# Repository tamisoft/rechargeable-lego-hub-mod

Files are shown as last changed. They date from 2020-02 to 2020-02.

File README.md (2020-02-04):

# LEGO HUB-mod, rechargable battery
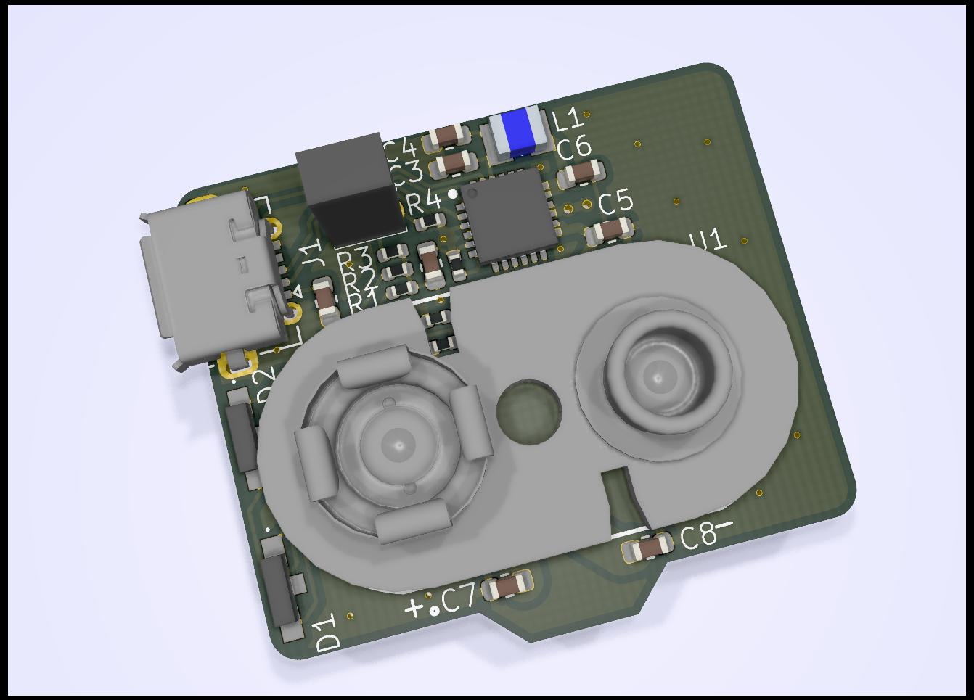
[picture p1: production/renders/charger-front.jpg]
Front Render


## Project
The Project was created using KiCAD 5.1.5.
Should be manufactured on a <0.8mm thick PCB (eg. oshpark's 2oz copper service).
The "production" directory has an "interactive bom" to assist with the hand assembly.

## Features
- USB charging at about 400mA
- TI BQ25886, 2A boost charger, optimized for 2S Li-Ion
- NTC
- connector for an 8.4V battery

Recommended battery:
[Soshine 9V 650mAh 6F22](https://lygte-info.dk/review/batteries9V/Soshine%209V%20LiIon%20650mAh%20(White)%20UK.html)

## Finished build
### Board assembled
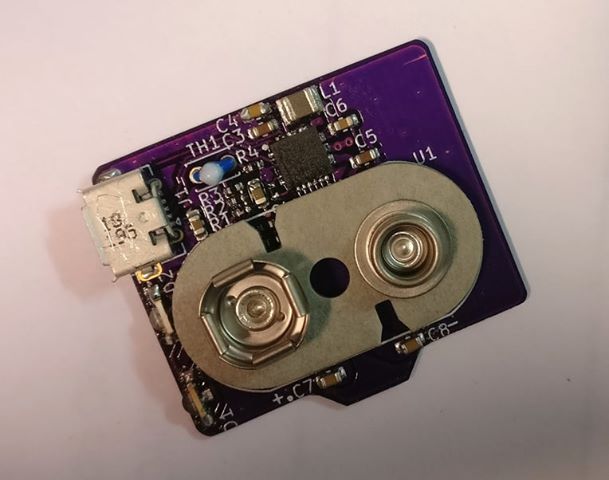
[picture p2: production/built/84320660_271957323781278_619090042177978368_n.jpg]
Board Assembled

### USB input
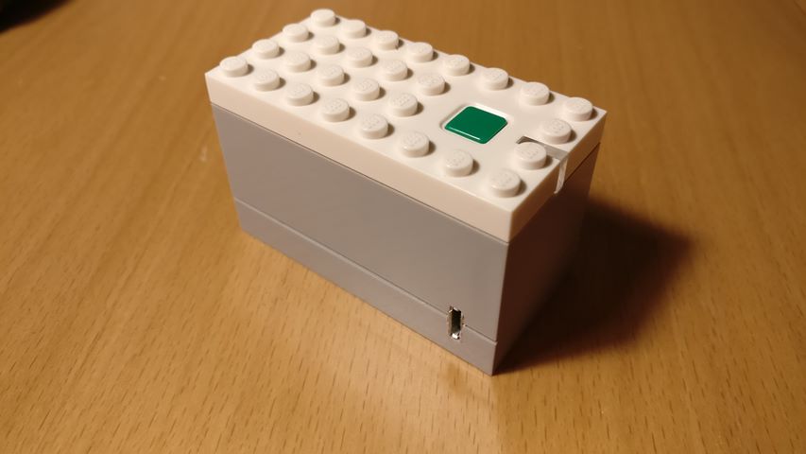
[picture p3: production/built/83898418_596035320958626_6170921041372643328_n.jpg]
USB input

### Charging indicators
- red: charging
- green: power

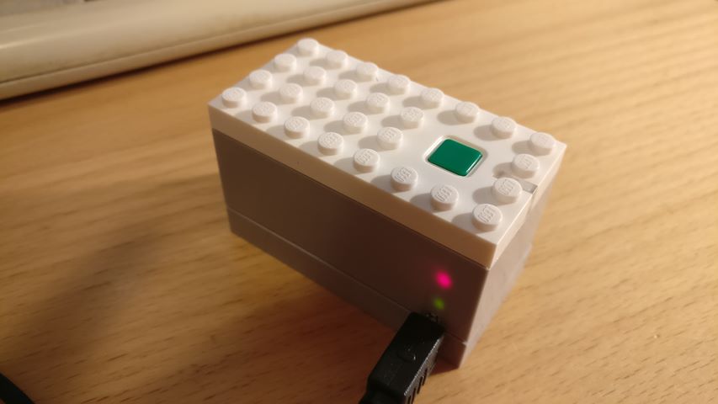
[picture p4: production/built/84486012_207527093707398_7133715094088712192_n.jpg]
Charging indicators


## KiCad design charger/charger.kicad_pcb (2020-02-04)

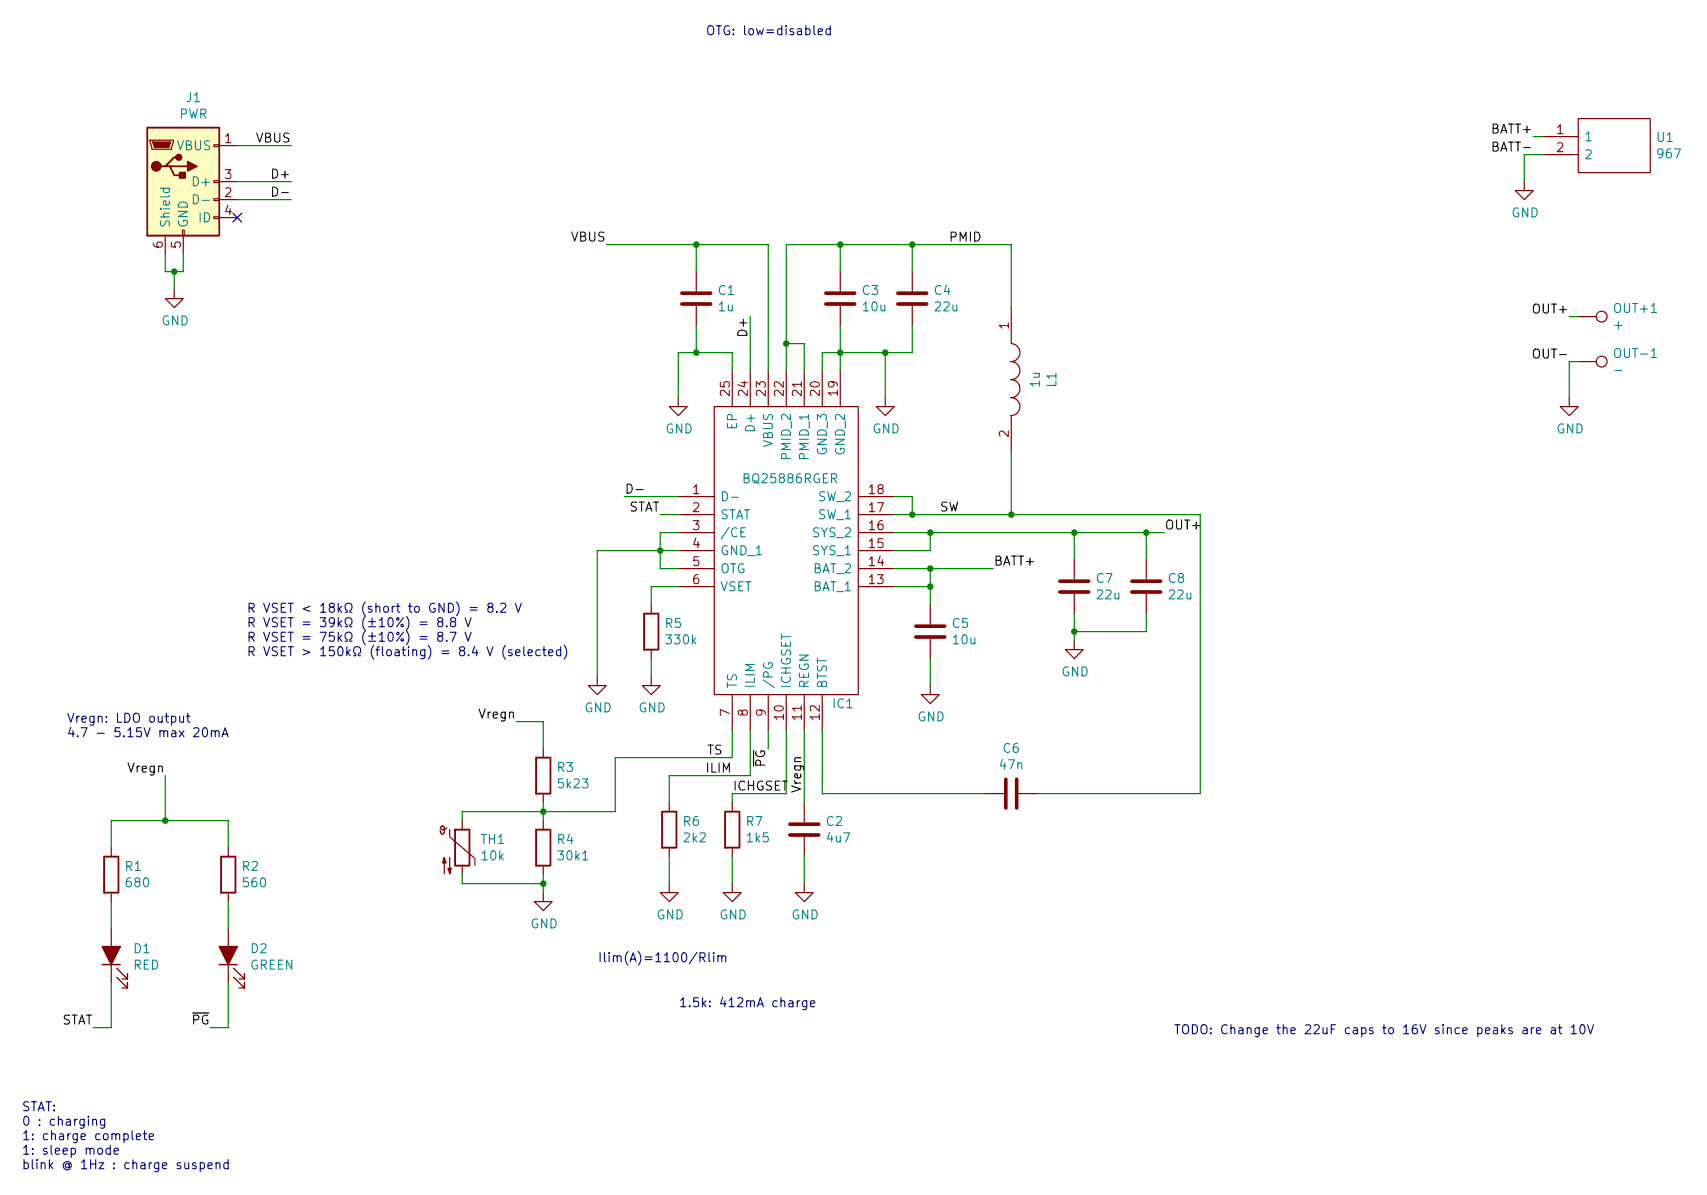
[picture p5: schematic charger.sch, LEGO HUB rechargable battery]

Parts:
C1: 1u; C_0603_1608Metric; MOUSER 603-CC603KPX7R7BB105
C2: 4u7; C_0603_1608Metric; MOUSER 963-EMK107ABJ475MA-T
C3, C5: 10u; C_0603_1608Metric; MOUSER 81-GRT188R61C106KE3D
C4, C7, C8: 22u; C_0603_1608Metric; MOUSER 81-ZRB18AR61A226ME1L
C6: 47n; C_0603_1608Metric; MOUSER 603-CC603KPX7R7BB473
D1: RED; HSMAC110; MOUSER 630-HSMH-C110
D2: GREEN; HSMAC110; MOUSER 630-HSMG-C110
IC1: BQ25886RGER; QFN50P400X400X100-25N; Mouser Part Number 595-BQ25886RGER
J1: PWR; USB_Micro-AB_Molex_47590-0001; MOUSER 538-47590-0001
L1: 1u; INDC2520X120N; Mouser Part Number 81-DFE252012F-1R0MP2
OUT+1: +; TestPoint_Pad_1.0x1.0mm
OUT-1: -; TestPoint_Pad_1.0x1.0mm
R1: 680; R_0402_1005Metric; MOUSER 667-ERJ-U02D6800X
R2: 560; R_0402_1005Metric; MOUSER 667-ERJ-2RHD5600X
R3: 5k23; R_0402_1005Metric; MOUSER 603-AC0402FR-075K23L
R4: 30k1; R_0402_1005Metric; MOUSER 667-ERJ-2RHD3012X
R5: 330k; R_0402_1005Metric; MOUSER 71-CRCW0402330KFKEDC
R6: 2k2; R_0402_1005Metric; MOUSER 279-CRGP0402F2K2
R7: 1k5; R_0402_1005Metric; MOUSER 71-CRCW04021K50FKEDC
TH1: 10k; 103AT2; MOUSER 954-103AT-2
U1: 967; Mouser Part Number 534-967

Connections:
/BATT+: C5.1, IC1.13 (BAT_1), IC1.14 (BAT_2), U1.1
/D+: IC1.24 (D+), J1.3 (D+)
/D-: IC1.1 (D-), J1.2 (D-)
/ICHGSET: IC1.10 (ICHGSET), R7.1
/ILIM: IC1.8 (ILIM), R6.1
/OUT+: C7.1, C8.1, IC1.15 (SYS_1), IC1.16 (SYS_2), OUT+1.1
/PMID: C3.1, C4.1, IC1.21 (PMID_1), IC1.22 (PMID_2), L1.1
/STAT: D1.1 (K), IC1.2 (STAT)
/SW: C6.1, IC1.17 (SW_1), IC1.18 (SW_2), L1.2
/TS: IC1.7 (TS), R3.2, R4.1, TH1.1
/VBUS: C1.1, IC1.23 (VBUS), J1.1 (VBUS)
/Vregn: C2.1, IC1.11 (REGN), R1.1, R2.1, R3.1
/~PG: D2.1 (K), IC1.9 (/PG)
GND: C1.2, C2.2, C3.2, C4.2, C5.2, C7.2, C8.2, IC1.3 (/CE), IC1.4 (GND_1), IC1.5 (OTG), IC1.19 (GND_2), IC1.20 (GND_3), IC1.25 (EP), J1.5 (GND), J1.6 (Shield), OUT-1.1, R4.2, R5.2, R6.2, R7.2, TH1.2, U1.2
unnamed: C6.2, IC1.12 (BTST)
unnamed: D1.2 (A), R1.2
unnamed: D2.2 (A), R2.2
unnamed: IC1.6 (VSET), R5.1

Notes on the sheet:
OTG: low=disabled
R VSET < 18kΩ (short to GND) = 8.2 V R VSET = 39kΩ (±10%) = 8.8 V R VSET = 75kΩ (±10%) = 8.7 V R VSET > 150kΩ (floating) = 8.4 V (selected)
STAT: 0 : charging 1: charge complete 1: sleep mode blink @ 1Hz : charge suspend
Vregn: LDO output 4.7 - 5.15V max 20mA
1.5k: 412mA charge
Ilim(A)=1100/Rlim
TODO: Change the 22uF caps to 16V since peaks are at 10V

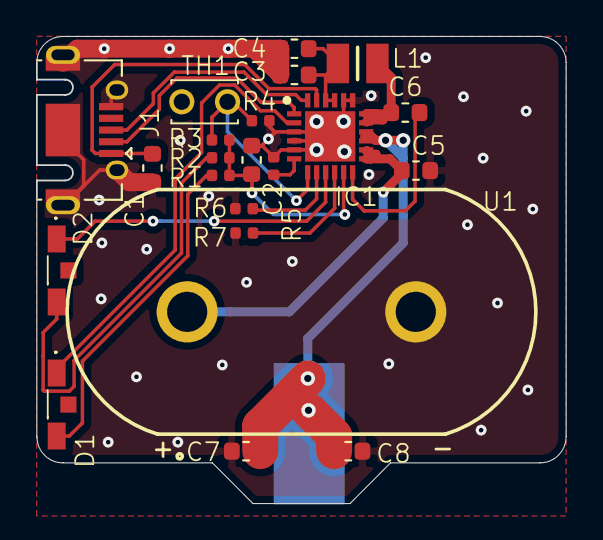
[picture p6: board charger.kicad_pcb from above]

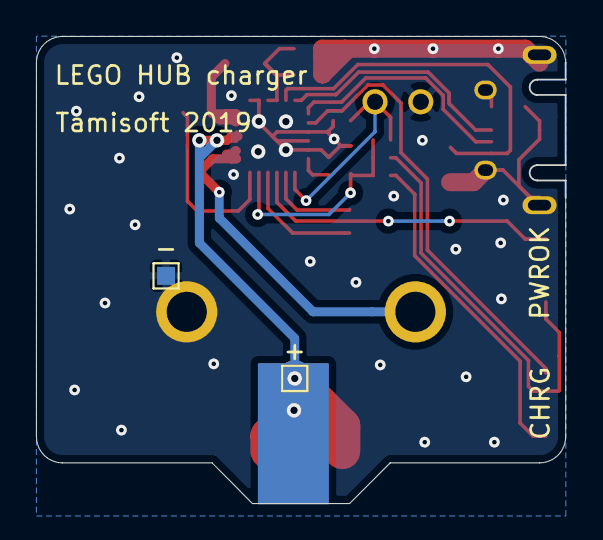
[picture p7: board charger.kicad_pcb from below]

Board: 2 copper layers, 29.4 x 26.0 mm, 24 parts (2 on the bottom side), 18 nets.
